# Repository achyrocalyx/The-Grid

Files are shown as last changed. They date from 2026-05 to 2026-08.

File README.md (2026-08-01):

# The-Grid
EC REX Small Build Project (Interactive LED Floor)

Funded in part by the Council for the Arts at MIT. [@artsatMIT](https://www.instagram.com/artsatmit/)


With generous support from [EasyEDA](https://easyeda.com/) and [JLCPCB](https://jlcpcb.com/) for PCB manufacturing.

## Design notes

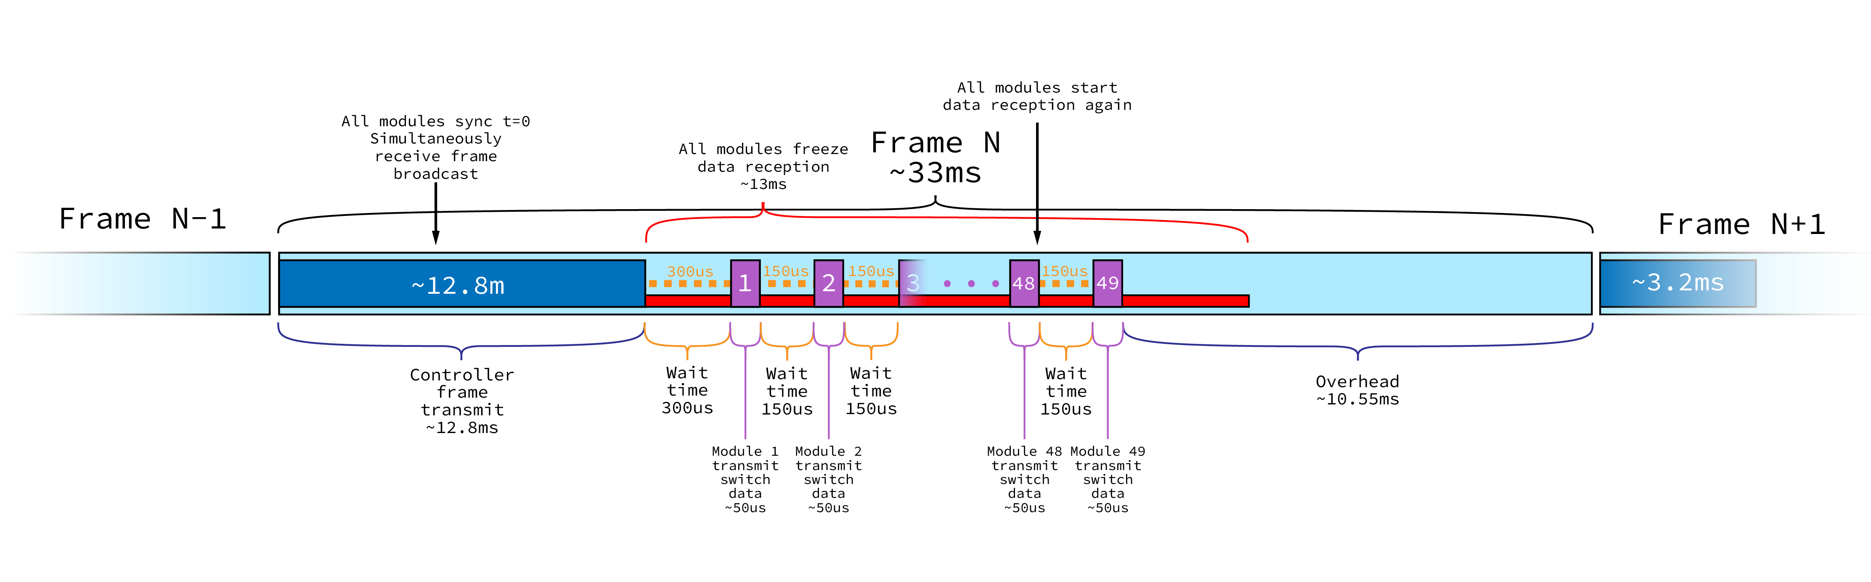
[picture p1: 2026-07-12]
FrameProtocolDraft2.png

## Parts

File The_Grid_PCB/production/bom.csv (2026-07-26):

Designator | Footprint | Quantity | Value | LCSC Part #
C1, C4, C6 | C_1206 | 3 | 4.7uF | C29823
C10, C11, C16, C17, C2, C3, C9 | C_0603 | 7 | 100nF | C14663
C12 | C_0805 | 1 | 1nF | C46653
C13 | C_0603 | 1 | 10pF | C1634
C14, C15 | C_1206 | 2 | 47uF | C96123
C18 | C_0805 | 1 | 10uF | C15850
C19 | C_0805 | 1 | 100nF | C28233
C5 | CP_Radial_D8.0mm_P3.50mm | 1 | 100uF | C112510
C7 | C_0805 | 1 | 10nF | C1710
C8 | C_0603 | 1 | 8.2nF | C1322360
D1 | D_0603 | 1 | LED | C2286
D2 | SOT-23 | 1 | CDSOT23-SM712 | C404012
D3 | D_SMA | 1 | SS34 | C8678
J1, J4 | TerminalBlock_MaiXu_MX126-5.0-02P_1x02_P5.00mm | 2 | Screw_Terminal_01x02 | C8404
J10, J11, J12, J13, J14, J15, J16, J5, J6, J7, J8, J9 | TerminalBlock_4Ucon_1x02_P3.50mm_Horizontal | 12 | Screw_Terminal_01x02 | C695629
J2, J3 | TerminalBlock_Xinya_XY308-2.54-3P_1x03_P2.54mm_Horizontal | 2 | Screw_Terminal_01x03 | C5188443
L1 | L_Bourns_SRP7028A_7.3x6.6mm | 1 | 8.2uH | C167222
Q1, Q10, Q11, Q12, Q2, Q3, Q4, Q5, Q6, Q7, Q8, Q9 | Q_SOT-23 | 12 | AO3400A | C20917
R1, R13 | R_0603 | 2 | 560Ω | C23204
R10, R12 | R_0603 | 2 | 200Ω | C8218
R11, R15, R16, R18, R2, R20, R22, R24, R26, R28, R3, R30, R32, R34, R36, R38, R40, R7, R8 | R_0603 | 19 | 10kΩ | C25804
R14 | R_0603 | 1 | 1.2kΩ | C22765
R17, R19, R21, R23, R25, R27, R29, R31, R33, R35, R37, R39 | R_0603 | 12 | 100Ω | C22775
R4, R5 | R_0603 | 2 | 10Ω | C22859
R9 | R_0603 | 1 | 68kΩ | C23231
TP1 | TestPoint_THTPad_D2.0mm_Drill1.0mm | 1 | RS485 RX
TP2 | TestPoint_THTPad_D2.0mm_Drill1.0mm | 1 | RS485 TX
TP3 | TestPoint_THTPad_D2.0mm_Drill1.0mm | 1 | 3V3
TP4 | TestPoint_THTPad_D2.0mm_Drill1.0mm | 1 | GND
TP5 | TestPoint_THTPad_D2.0mm_Drill1.0mm | 1 | 5V
U1 | STM32BluePill | 1 | STM32 Blue Pill
U2 | SOIC-8_3.9x4.9mm_P1.27mm | 1 | THDV1520 | C882408
U3 | SOIC127P600X175-8N | 1 | TPS54331DR | C9865

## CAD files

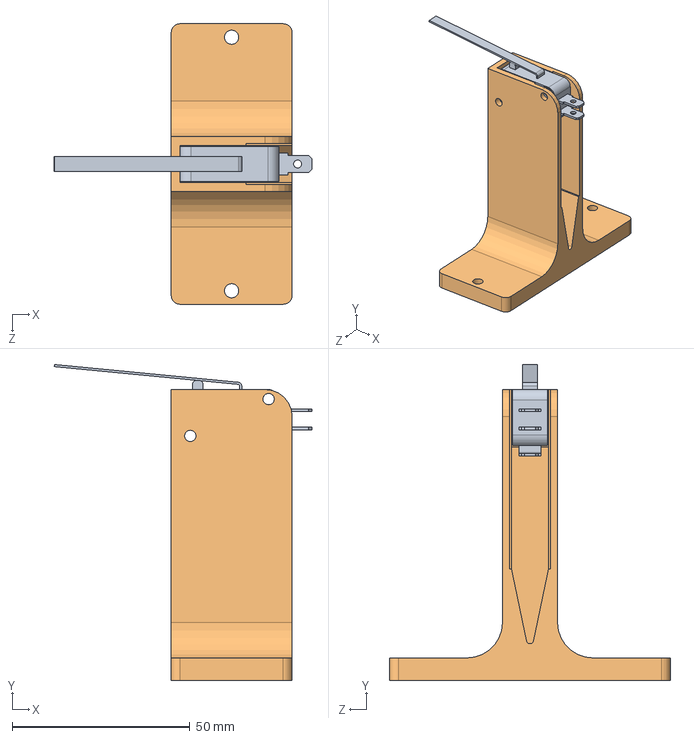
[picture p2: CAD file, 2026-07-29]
CAD/microswitch_assembly.SLDASM
72.5 x 88.9 x 79.0 mm
aliexpressMount
KW7_microswitch

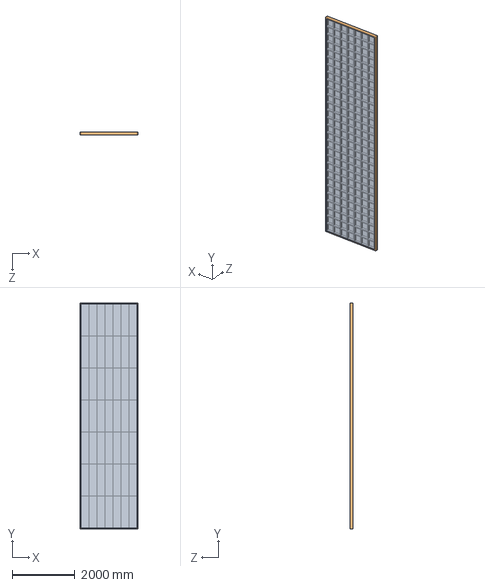
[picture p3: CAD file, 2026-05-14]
CAD/fullAssembly.SLDASM
1854.2 x 7188.2 x 88.9 mm
encloseDotModules
module cad REAL x 49

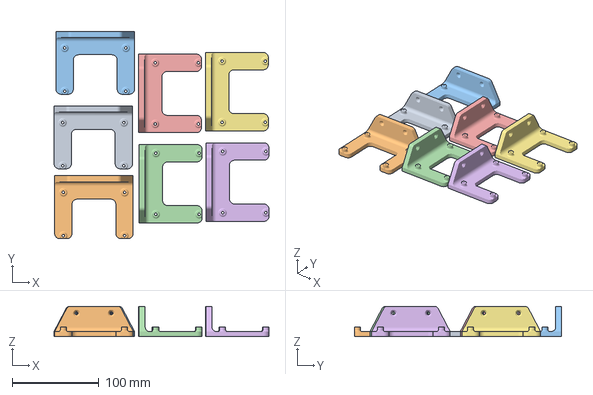
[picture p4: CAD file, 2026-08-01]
CAD/Printfiles/PCB_shelf_PRINTFILE.3mf
247.3 x 238.7 x 35.0 mm
PCB_shelf_step.STEP x 7

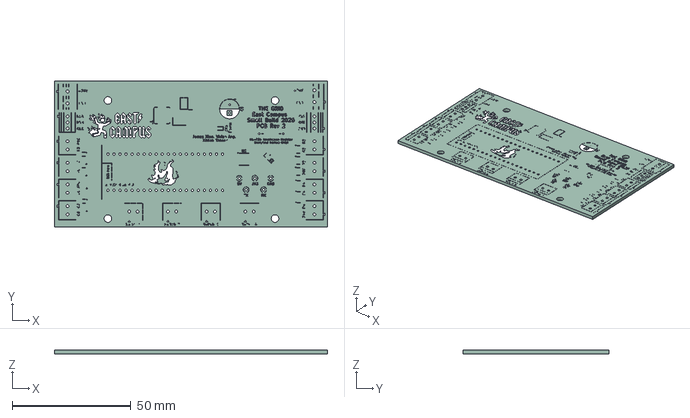
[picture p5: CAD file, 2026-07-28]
The_Grid_PCB/The_Grid_PCB.step
115.0 x 61.5 x 1.66 mm
The46A9_silkscreen x 2
The46A9_PCB

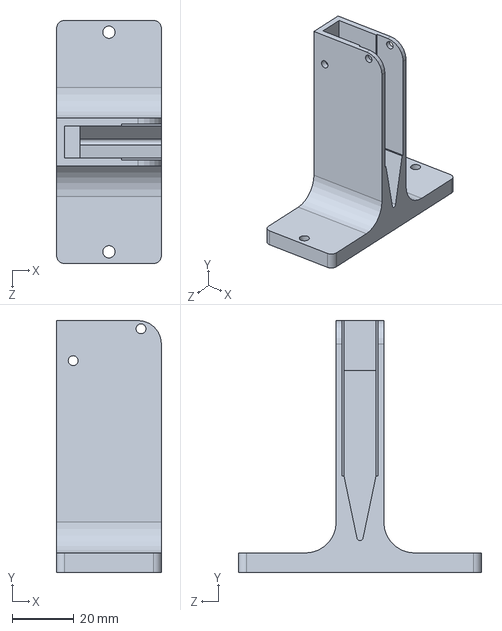
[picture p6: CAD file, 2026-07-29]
CAD/aliexpressMount.SLDPRT
34.1 x 81.9 x 79.0 mm

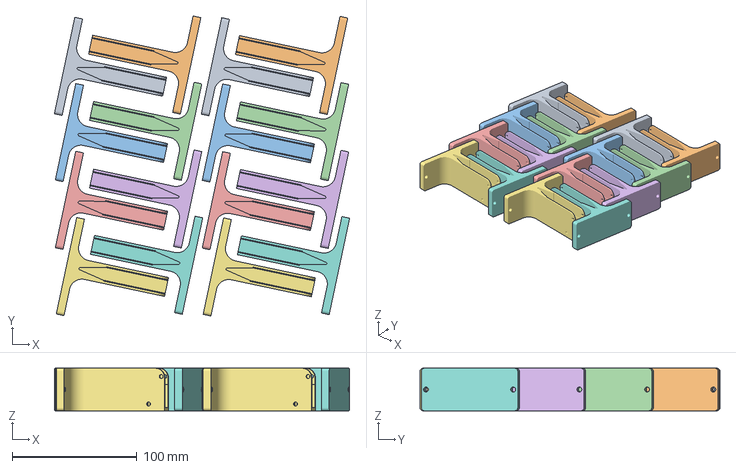
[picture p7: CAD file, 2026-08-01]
CAD/Printfiles/microswitch_mount_PRINTFILE.3mf
236.5 x 240.2 x 34.1 mm
aliexpress_mount_step.STEP x 16

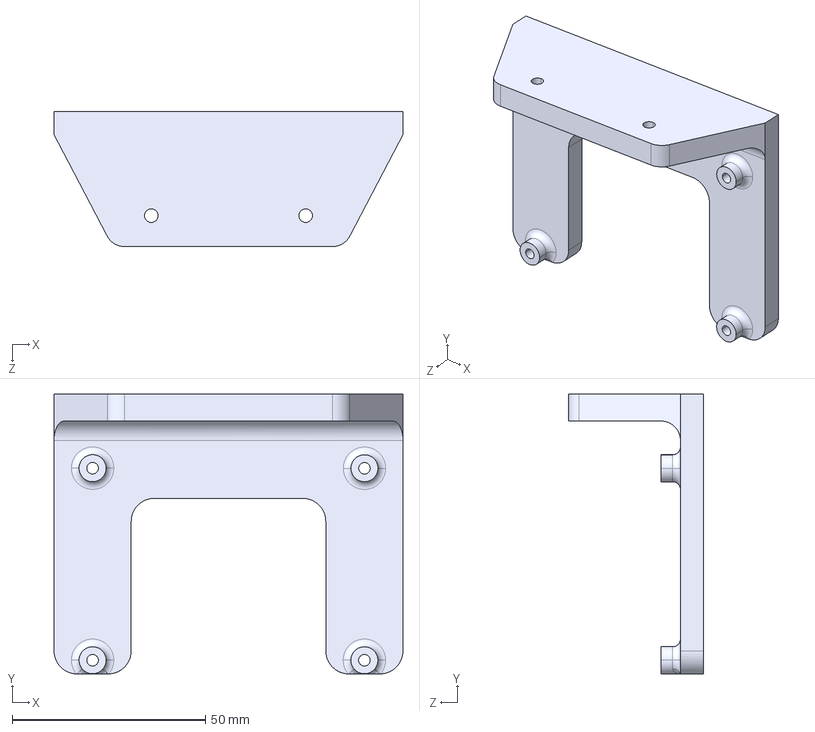
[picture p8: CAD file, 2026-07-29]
CAD/PCB_shelf_step.STEP
90.4 x 72.5 x 35.0 mm

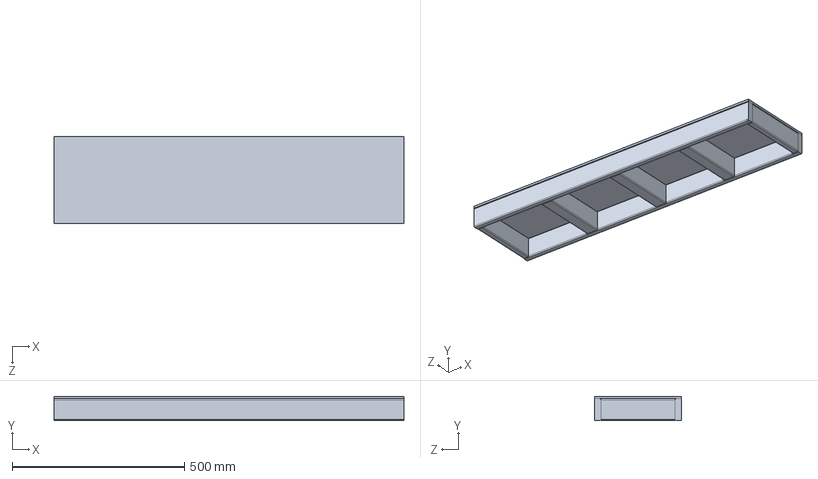
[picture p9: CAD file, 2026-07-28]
CAD/module cad REAL.SLDPRT
1016.0 x 69.8 x 254.0 mm

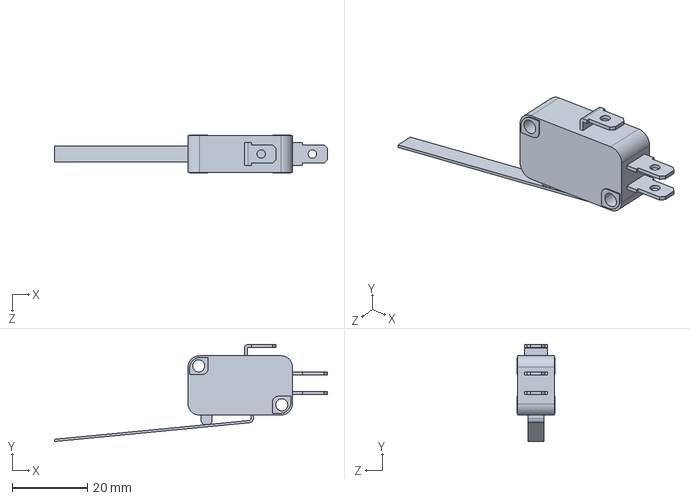
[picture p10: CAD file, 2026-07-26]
CAD/KW7_microswitch.SLDPRT
72.5 x 25.8 x 10.2 mm

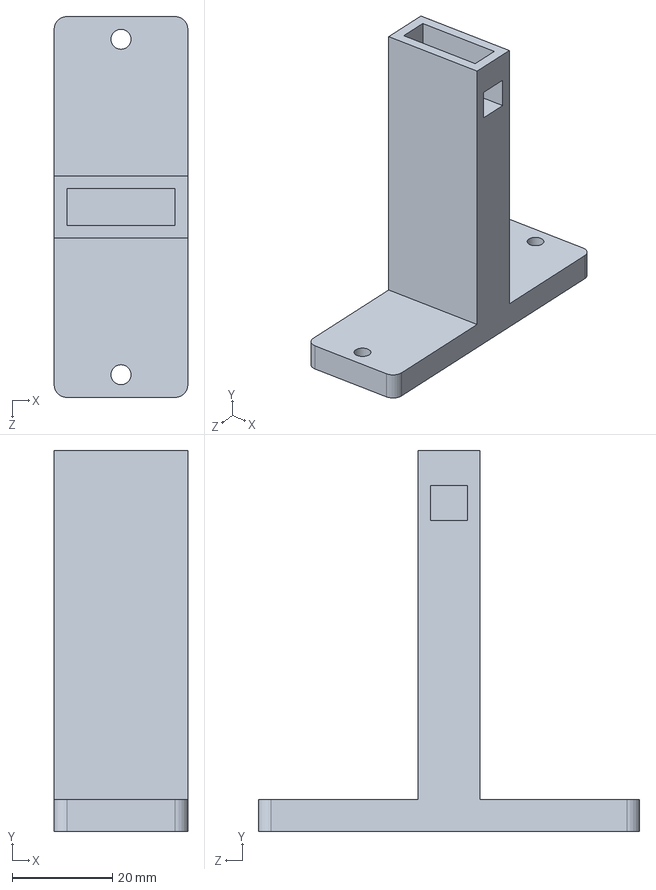
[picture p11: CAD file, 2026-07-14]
CAD/amazonMount.SLDPRT
26.7 x 75.9 x 75.9 mm

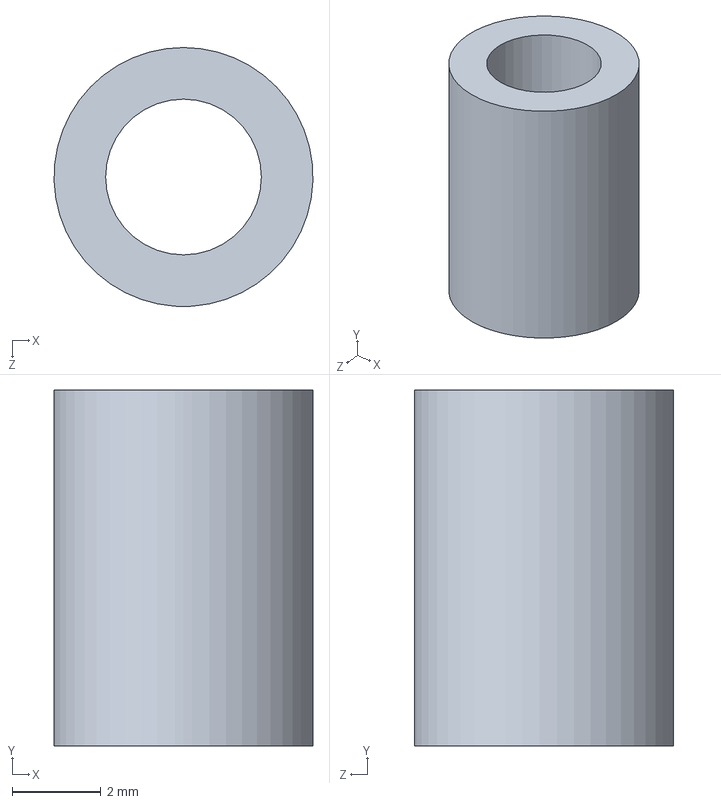
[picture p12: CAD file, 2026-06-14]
CAD/standoff.SLDPRT
5.82 x 8.00 x 5.82 mm

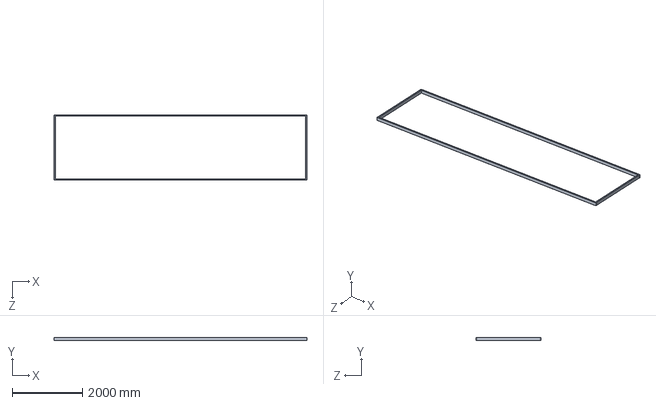
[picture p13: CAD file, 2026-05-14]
CAD/encloseDotModules.SLDPRT
7188.2 x 88.9 x 1854.2 mm

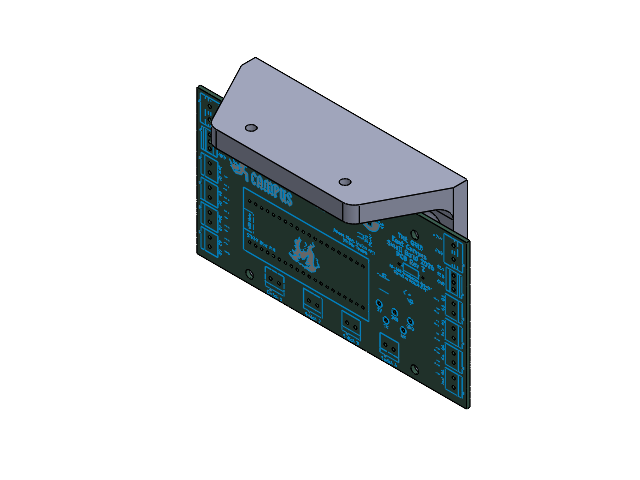
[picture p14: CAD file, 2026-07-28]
CAD/PCB_shelf_assembly.SLDASM
The46A9_silkscreen.step
The46A9_silkscreen-0.step
The46A9_PCB.step
PCB_shelf

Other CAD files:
CAD/aliexpress_mount_step.STEP
CAD/PCB_shelf.SLDPRT
CAD/standoff3MF.3MF
CAD/PCB_shelf_step.3mf
CAD/aliexpressMount.3MF

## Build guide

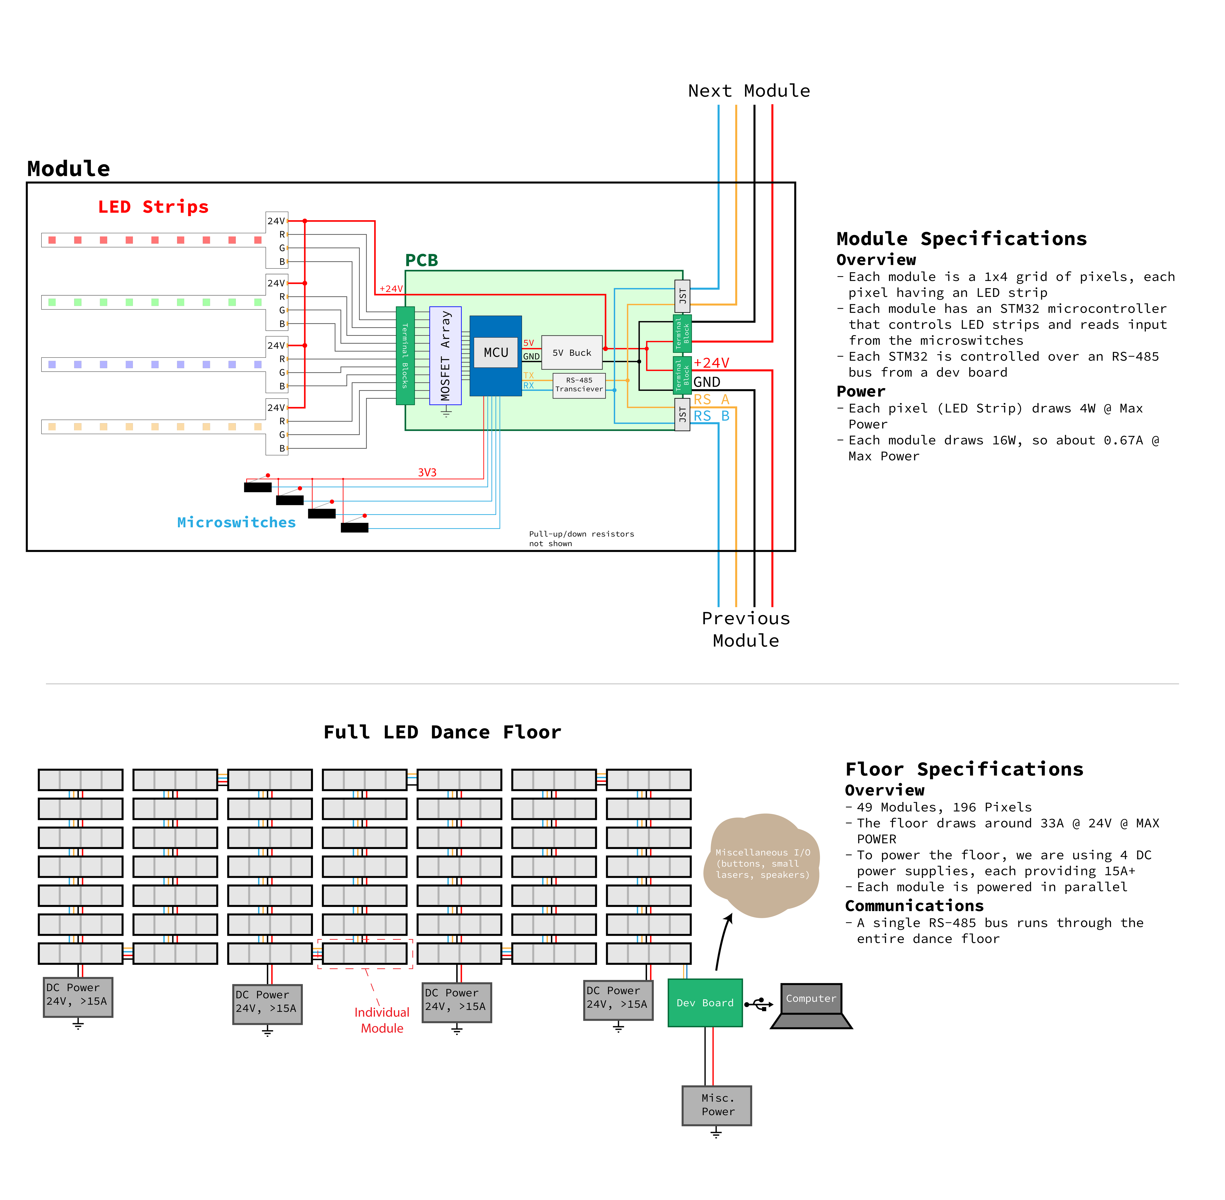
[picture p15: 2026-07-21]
WiringDiagramDraft5.png

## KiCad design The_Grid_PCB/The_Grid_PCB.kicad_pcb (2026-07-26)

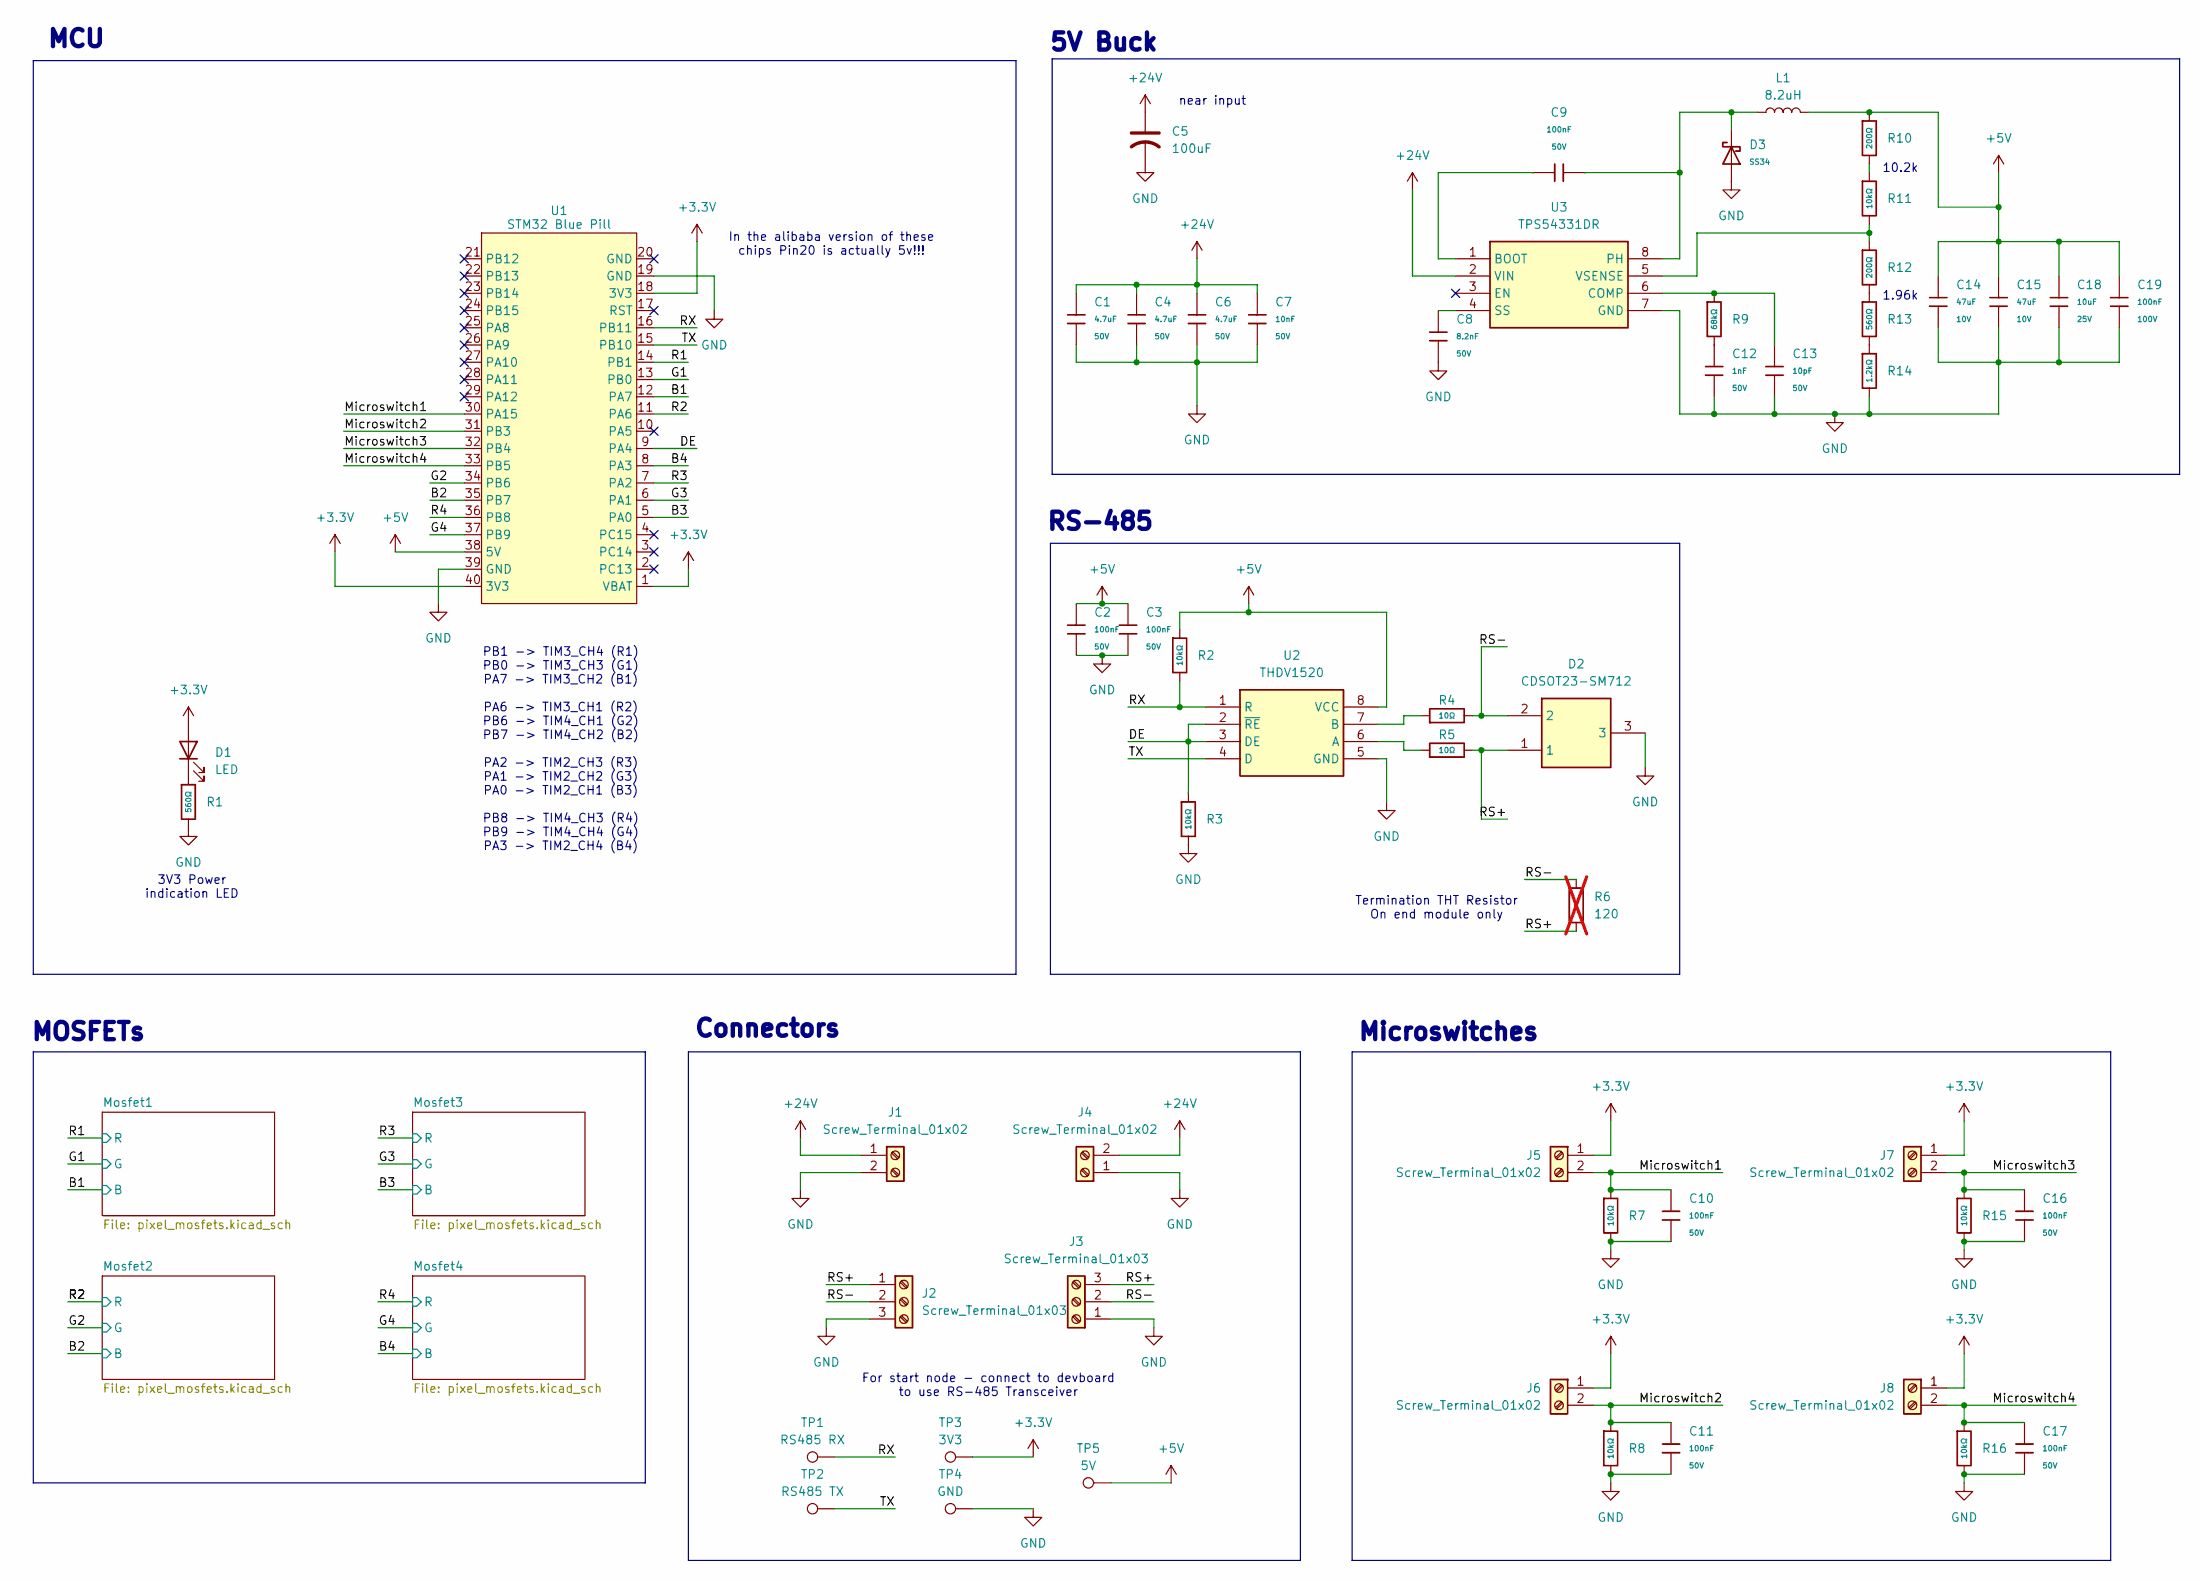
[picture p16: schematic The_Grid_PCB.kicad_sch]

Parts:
C1, C4, C6: 4.7uF; C_1206; Voltage Rated 50V; Tolerance ±10%; Part 1206B475K500NT; LCSC C29823
C2, C3, C9, C10, C11, C16, C17: 100nF; C_0603; Voltage Rated 50V; Tolerance ±10%; Part CC0603KRX7R9BB104; LCSC C14663
C5: 100uF; CP_Radial_D8.0mm_P3.50mm; LCSC C112510
C7: 10nF; C_0805; Voltage Rated 50V; Tolerance ±10%; Part CL21B103KBANNNC; LCSC C1710
C8: 8.2nF; C_0603; Voltage Rated 50V; Tolerance ±10%; Part 0603B822K500NT; LCSC C1322360
C12: 1nF; C_0805; Voltage Rated 50V; Tolerance ±10%; Part CL21B102KBCNNNC; LCSC C46653
C13: 10pF; C_0603; Voltage Rated 50V; Tolerance ±5%; Part CL10C100JB8NNNC; LCSC C1634
C14, C15: 47uF; C_1206; Voltage Rated 10V; Tolerance ±20%; Part CL31A476MPHNNNE; LCSC C96123
C18: 10uF; C_0805; Voltage Rated 25V; Tolerance ±10%; Part CL21A106KAYNNNE; LCSC C15850
C19: 100nF; C_0805; Voltage Rated 100V; Tolerance ±10%; Part CL21B104KCFNNNE; LCSC C28233
D1: LED; D_0603; LCSC C2286
D2: CDSOT23-SM712; SOT-23; Manufacturer_Part_Number CDSOT23-SM712; Mouser Part Number 652-CDSOT23-SM712
D3: SS34; D_SMA; Forward Voltage (Vf@If) 550mV@3A; Reverse Voltage (Vr) 40V; Part SS34; LCSC C8678
J1, J4: Screw_Terminal_01x02; TerminalBlock_MaiXu_MX126-5.0-02P_1x02_P5.00mm; LCSC C8404
J2, J3: Screw_Terminal_01x03; TerminalBlock_Xinya_XY308-2.54-3P_1x03_P2.54mm_Horizontal; LCSC C5188443
J5, J6, J7, J8: Screw_Terminal_01x02; TerminalBlock_4Ucon_1x02_P3.50mm_Horizontal; LCSC C695629
L1: 8.2uH; L_Bourns_SRP7028A_7.3x6.6mm; LCSC C167222
R1, R13: 560Ω; R_0603; Overload Voltage (Max) 75V; Tolerance ±1%; Part 0603WAF5600T5E; LCSC C23204
R2, R3, R7, R8, R11, R15, R16: 10kΩ; R_0603; Overload Voltage (Max) 75V; Tolerance ±1%; Part 0603WAF1002T5E; LCSC C25804
R4, R5: 10Ω; R_0603; Overload Voltage (Max) 75V; Tolerance ±1%; Part 0603WAF100JT5E; LCSC C22859
R6: 120; R_Axial_DIN0207_L6.3mm_D2.5mm_P10.16mm_Horizontal; not fitted
R9: 68kΩ; R_0603; Overload Voltage (Max) 75V; Tolerance ±1%; Part 0603WAF6802T5E; LCSC C23231
R10, R12: 200Ω; R_0603; Overload Voltage (Max) 75V; Tolerance ±1%; Part 0603WAF2000T5E; LCSC C8218
R14: 1.2kΩ; R_0603; Overload Voltage (Max) 75V; Tolerance ±1%; Part 0603WAF1201T5E; LCSC C22765
TP1: RS485 RX; TestPoint_THTPad_D2.0mm_Drill1.0mm
TP2: RS485 TX; TestPoint_THTPad_D2.0mm_Drill1.0mm
TP3: 3V3; TestPoint_THTPad_D2.0mm_Drill1.0mm
TP4: GND; TestPoint_THTPad_D2.0mm_Drill1.0mm
TP5: 5V; TestPoint_THTPad_D2.0mm_Drill1.0mm
U1: STM32 Blue Pill; STM32BluePill
U2: THDV1520; SOIC-8_3.9x4.9mm_P1.27mm; Manufacturer_Part_Number THDV1520; LCSC C882408
U3: TPS54331DR; SOIC127P600X175-8N; Manufacturer_Part_Number TPS54331DR; Mouser Part Number 595-TPS54331DR

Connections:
+3.3V: D1.2 (A), J5.1, J6.1, J7.1, J8.1, TP3.1 (1_1), U1.1 (VBAT), U1.18 (3V3), U1.40 (3V3)
+5V: C2.1, C3.1, C14.2, C15.2, C18.1, C19.1, L1.2, R2.1, R10.1, TP5.1 (1_1), U1.38 (5V), U2.8 (VCC)
+24V: C1.1, C4.1, C5.1, C6.1, C7.1, J1.1, J4.2, U3.2 (VIN); also elsewhere on the board
/B1: U1.12 (PA7); also elsewhere on the board
/B2: U1.35 (PB7); also elsewhere on the board
/B3: U1.5 (PA0); also elsewhere on the board
/B4: U1.8 (PA3); also elsewhere on the board
/DE: R3.1, U1.9 (PA4), U2.2 (~RE), U2.3 (DE)
/G1: U1.13 (PB0); also elsewhere on the board
/G2: U1.34 (PB6); also elsewhere on the board
/G3: U1.6 (PA1); also elsewhere on the board
/G4: U1.37 (PB9); also elsewhere on the board
/Microswitch1: C10.1, J5.2, R7.1, U1.30 (PA15)
/Microswitch2: C11.1, J6.2, R8.1, U1.31 (PB3)
/Microswitch3: C16.1, J7.2, R15.1, U1.32 (PB4)
/Microswitch4: C17.1, J8.2, R16.1, U1.33 (PB5)
/R1: U1.14 (PB1); also elsewhere on the board
/R2: U1.11 (PA6); also elsewhere on the board
/R3: U1.7 (PA2); also elsewhere on the board
/R4: U1.36 (PB8); also elsewhere on the board
/RS+: D2.1, J2.1, J3.3, R5.2, R6.2
/RS-: D2.2, J2.2, J3.2, R4.2, R6.1
/RX: R2.2, TP1.1 (1_1), U1.16 (PB11), U2.1 (R)
/TX: TP2.1 (1_1), U1.15 (PB10), U2.4 (D)
GND: C1.2, C2.2, C3.2, C4.2, C5.2, C6.2, C7.2, C8.2, C10.2, C11.2, C12.2, C13.2, C14.1, C15.1, C16.2, C17.2, C18.2, C19.2, D2.3, D3.2, J1.2, J2.3, J3.1, J4.1, R1.2, R3.2, R7.2, R8.2, R14.2, R15.2, R16.2, TP4.1 (1_1), U1.19 (GND), U1.39 (GND), U2.5 (GND), U3.7 (GND); also elsewhere on the board
unnamed: C12.1, R9.2
unnamed: D1.1 (K), R1.1
unnamed: R10.2, R11.1
unnamed: R12.2, R13.1
unnamed: R13.2, R14.1
unnamed: R5.1, U2.6 (A)
unnamed: R4.1, U2.7 (B)
unnamed: C9.1, U3.1 (BOOT)
unnamed: C13.1, R9.1, U3.6 (COMP)
unnamed: C9.2, D3.1, L1.1, U3.8 (PH)
unnamed: C8.1, U3.4 (SS)
unnamed: R11.2, R12.1, U3.5 (VSENSE)

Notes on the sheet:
RS-485
Connectors
1.96k
In the alibaba version of these chips Pin20 is actually 5v!!!
For start node - connect to devboard to use RS-485 Transceiver
3V3 Power indication LED
10.2k
5V Buck
near input
PB1 -> TIM3_CH4 (R1) PB0 -> TIM3_CH3 (G1) PA7 -> TIM3_CH2 (B1) PA6 -> TIM3_CH1 (R2) PB6 -> TIM4_CH1 (G2) PB7 -> TIM4_CH2 (B2) PA2 -> TIM2_CH3 (R3) PA1 -> TIM2_CH2 (G3) PA0 -> TIM2_CH1 (B3) PB8 -> TIM4_CH3 (R4) PB9 -> TIM4_CH4 (G4) PA3 -> TIM2_CH4 (B4)
MOSFETs
MCU
Termination THT Resistor On end module only
Microswitches

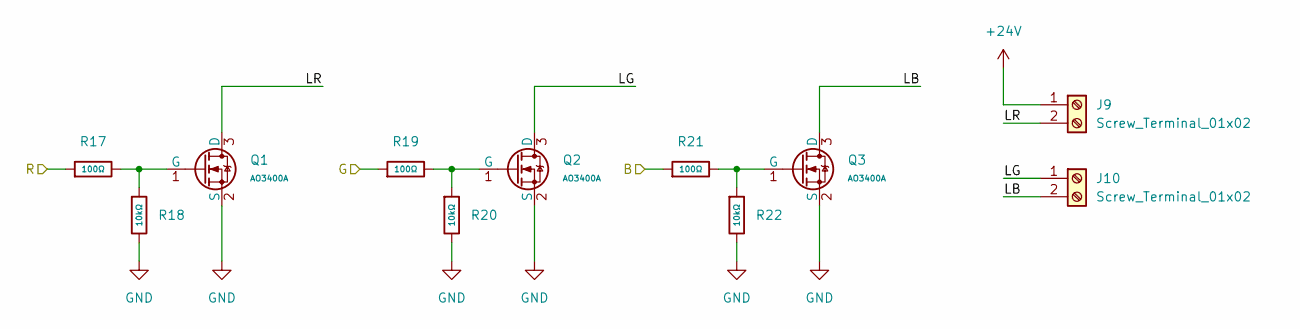
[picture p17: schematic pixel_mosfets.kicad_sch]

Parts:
J9, J10: Screw_Terminal_01x02; TerminalBlock_4Ucon_1x02_P3.50mm_Horizontal; LCSC C695629
Q1, Q2, Q3: AO3400A; Q_SOT-23; Part AO3400A; LCSC C20917
R17, R19, R21: 100Ω; R_0603; Overload Voltage (Max) 75V; Tolerance ±1%; Part 0603WAF1000T5E; LCSC C22775
R18, R20, R22: 10kΩ; R_0603; Overload Voltage (Max) 75V; Tolerance ±1%; Part 0603WAF1002T5E; LCSC C25804

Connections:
+24V: J9.1; also elsewhere on the board
/B1: R21.1; also elsewhere on the board
/G1: R19.1; also elsewhere on the board
/Mosfet1/LB: J10.2, Q3.3 (D)
/Mosfet1/LG: J10.1, Q2.3 (D)
/Mosfet1/LR: J9.2, Q1.3 (D)
/R1: R17.1; also elsewhere on the board
GND: Q1.2 (S), Q2.2 (S), Q3.2 (S), R18.2, R20.2, R22.2; also elsewhere on the board
unnamed: Q1.1 (G), R17.2, R18.1
unnamed: Q2.1 (G), R19.2, R20.1
unnamed: Q3.1 (G), R21.2, R22.1

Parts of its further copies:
J11, J12, J13, J14, J15, J16: Screw_Terminal_01x02; TerminalBlock_4Ucon_1x02_P3.50mm_Horizontal; LCSC C695629
Q4, Q5, Q6, Q7, Q8, Q9, Q10, Q11, Q12: AO3400A; Q_SOT-23; Part AO3400A; LCSC C20917
R23, R25, R27, R29, R31, R33, R35, R37, R39: 100Ω; R_0603; Overload Voltage (Max) 75V; Tolerance ±1%; Part 0603WAF1000T5E; LCSC C22775
R24, R26, R28, R30, R32, R34, R36, R38, R40: 10kΩ; R_0603; Overload Voltage (Max) 75V; Tolerance ±1%; Part 0603WAF1002T5E; LCSC C25804

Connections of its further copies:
+24V: J11.1, J13.1, J15.1; also elsewhere on the board
/B2: R27.1; also elsewhere on the board
/B3: R33.1; also elsewhere on the board
/B4: R39.1; also elsewhere on the board
/G2: R25.1; also elsewhere on the board
/G3: R31.1; also elsewhere on the board
/G4: R37.1; also elsewhere on the board
/Mosfet2/LB: J12.2, Q6.3 (D)
/Mosfet2/LG: J12.1, Q5.3 (D)
/Mosfet2/LR: J11.2, Q4.3 (D)
/Mosfet3/LB: J14.2, Q9.3 (D)
/Mosfet3/LG: J14.1, Q8.3 (D)
/Mosfet3/LR: J13.2, Q7.3 (D)
/Mosfet4/LB: J16.2, Q12.3 (D)
/Mosfet4/LG: J16.1, Q11.3 (D)
/Mosfet4/LR: J15.2, Q10.3 (D)
/R2: R23.1; also elsewhere on the board
/R3: R29.1; also elsewhere on the board
/R4: R35.1; also elsewhere on the board
GND: Q4.2 (S), Q5.2 (S), Q6.2 (S), Q7.2 (S), Q8.2 (S), Q9.2 (S), Q10.2 (S), Q11.2 (S), Q12.2 (S), R24.2, R26.2, R28.2, R30.2, R32.2, R34.2, R36.2, R38.2, R40.2; also elsewhere on the board
unnamed: Q4.1 (G), R23.2, R24.1
unnamed: Q5.1 (G), R25.2, R26.1
unnamed: Q6.1 (G), R27.2, R28.1
unnamed: Q7.1 (G), R29.2, R30.1
unnamed: Q8.1 (G), R31.2, R32.1
unnamed: Q9.1 (G), R33.2, R34.1
unnamed: Q10.1 (G), R35.2, R36.1
unnamed: Q11.1 (G), R37.2, R38.1
unnamed: Q12.1 (G), R39.2, R40.1

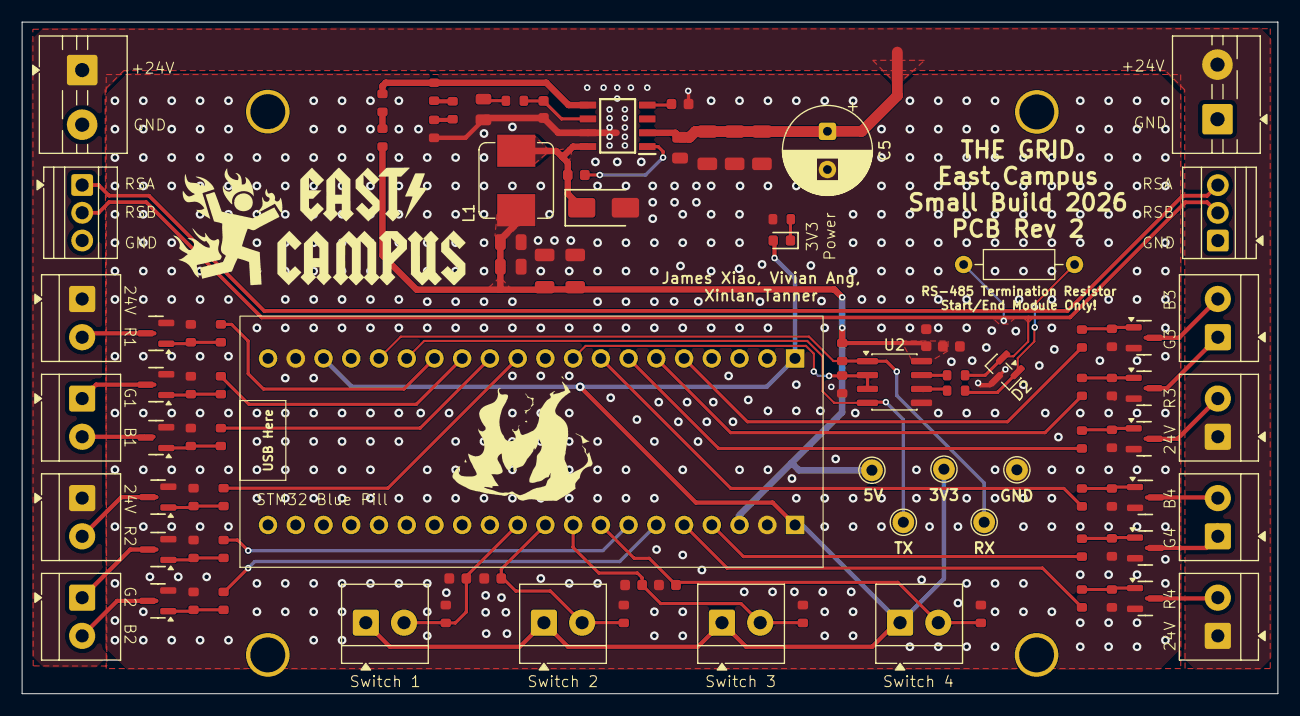
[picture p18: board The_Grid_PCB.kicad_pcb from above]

Board: 2 copper layers, 115.0 x 61.5 mm, 99 parts (0 on the bottom side), 61 nets.

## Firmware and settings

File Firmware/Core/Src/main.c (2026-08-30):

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
/* Includes ------------------------------------------------------------------*/
#include "main.h"

/* USER CODE BEGIN Includes */
#define MODULE_ID 7

/* USER CODE END Includes */

/* USER CODE BEGIN PD */
#define FRAME_DATA_LENGTH 589 // bytes
#define SWITCH_DATA_LENGTH 2 // bytes
/* USER CODE END PD */

TIM_HandleTypeDef htim1;
TIM_HandleTypeDef htim2;
TIM_HandleTypeDef htim3;
TIM_HandleTypeDef htim4;

UART_HandleTypeDef huart3;
DMA_HandleTypeDef hdma_usart3_rx;

/* USER CODE BEGIN PV */
uint8_t uart_rx_buffer[FRAME_DATA_LENGTH]; //rx buffer is 589 bytes
uint8_t uart_tx_buffer[SWITCH_DATA_LENGTH]; //tx buffer is 2 bytes

uint8_t microswitch[4] = {0}; //0 is off, 1 is on
uint8_t microswitch_off_next_cycle[4] = {0}; //set microswitch to be off on the next frame cycle

uint8_t microswitch_reported[4] = {0}; // reported values we send back to computer

uint8_t led_color_1[3]; // led color pixel [R val, G val, B val]
uint8_t led_color_2[3];
uint8_t led_color_3[3];
uint8_t led_color_4[3];

volatile uint8_t potentialMan[4] = {0}; // potentially microswitch may be on. slop variable to move while loop into main :(
volatile uint32_t timeStart[4] = {0};

volatile uint8_t resyncing = 0;
uint8_t sync_byte;

// state enums - idle, waiting, transmitted,
typedef enum {
	IDLE,
	WAITING,
	TRANSMITTED
} State;

typedef enum {
	RED,
	GREEN,
	BLUE
} Color;

State state = IDLE;


/* USER CODE END PV */

void SystemClock_Config(void);
static void MX_GPIO_Init(void);
static void MX_DMA_Init(void);
static void MX_TIM2_Init(void);
static void MX_TIM3_Init(void);
static void MX_TIM4_Init(void);
static void MX_USART3_UART_Init(void);
static void MX_TIM1_Init(void);
/* USER CODE BEGIN 0 */

/*== LED TIMER CHANNEL REFERENCE ==
PB1 -> TIM3_CH4 (R1)
PB0 -> TIM3_CH3 (G1)
PA7 -> TIM3_CH2 (B1)

PA6 -> TIM3_CH1 (R2)
PB6 -> TIM4_CH1 (G2)
PB7 -> TIM4_CH2 (B2)

PA2 -> TIM2_CH3 (R3)
PA1 -> TIM2_CH2 (G3)
PA0 -> TIM2_CH1 (B3)

PB8 -> TIM4_CH3 (R4)
PB9 -> TIM4_CH4 (G4)
PA3 -> TIM2_CH4 (B4) */

void command_led_1(uint8_t r, uint8_t g, uint8_t b) {
	led_color_1[RED] = r; // check protocol sheet for more information, sets colors to what is put in buffer (based on module ID)
	led_color_1[GREEN] = g;
	led_color_1[BLUE] = b;

	__HAL_TIM_SET_COMPARE(&htim3, TIM_CHANNEL_4, r);
	__HAL_TIM_SET_COMPARE(&htim3, TIM_CHANNEL_3, g);
	__HAL_TIM_SET_COMPARE(&htim3, TIM_CHANNEL_2, b);
}

void command_led_2(uint8_t r, uint8_t g, uint8_t b) {
	led_color_2[RED] = r;
	led_color_2[GREEN] = g;
	led_color_2[BLUE] = b;

	__HAL_TIM_SET_COMPARE(&htim3, TIM_CHANNEL_1, r);
	__HAL_TIM_SET_COMPARE(&htim4, TIM_CHANNEL_1, g);
	__HAL_TIM_SET_COMPARE(&htim4, TIM_CHANNEL_2, b);
}

void command_led_3(uint8_t r, uint8_t g, uint8_t b) {
	led_color_3[RED] = r;
	led_color_3[GREEN] = g;
	led_color_3[BLUE] = b;

	__HAL_TIM_SET_COMPARE(&htim2, TIM_CHANNEL_3, r);
	__HAL_TIM_SET_COMPARE(&htim2, TIM_CHANNEL_2, g);
	__HAL_TIM_SET_COMPARE(&htim2, TIM_CHANNEL_1, b);
}

void command_led_4(uint8_t r, uint8_t g, uint8_t b) {
	led_color_4[RED] = r;
	led_color_4[GREEN] = g;
	led_color_4[BLUE] = b;

	__HAL_TIM_SET_COMPARE(&htim4, TIM_CHANNEL_3, r);
	__HAL_TIM_SET_COMPARE(&htim4, TIM_CHANNEL_4, g);
	__HAL_TIM_SET_COMPARE(&htim2, TIM_CHANNEL_4, b);
}

/* USER CODE END 0 */

/**
  * @brief  The application entry point.
  * @retval int
  */
int main(void)
{

  /* MCU Configuration--------------------------------------------------------*/

  /* Reset of all peripherals, Initializes the Flash interface and the Systick. */
  HAL_Init();

  /* Configure the system clock */
  SystemClock_Config();

  /* USER CODE BEGIN SysInit */
  __HAL_RCC_AFIO_CLK_ENABLE();
  __HAL_AFIO_REMAP_SWJ_NOJTAG();   // releases JTAG-only pins (PA15, PB3, PB4) for GPIO use, keeps SWD (PA13/PA14) alive for debugging
  /* USER CODE END SysInit */

  /* Initialize all configured peripherals */
  MX_GPIO_Init();
  MX_DMA_Init();
  MX_TIM2_Init();
  MX_TIM3_Init();
  MX_TIM4_Init();
  MX_USART3_UART_Init();
  MX_TIM1_Init();
  /* USER CODE BEGIN 2 */

  /* Enable PWM Timers */
    HAL_TIM_PWM_Start(&htim2, TIM_CHANNEL_1);
    HAL_TIM_PWM_Start(&htim2, TIM_CHANNEL_2);
    HAL_TIM_PWM_Start(&htim2, TIM_CHANNEL_3);
    HAL_TIM_PWM_Start(&htim2, TIM_CHANNEL_4);

    HAL_TIM_PWM_Start(&htim3, TIM_CHANNEL_1);
    HAL_TIM_PWM_Start(&htim3, TIM_CHANNEL_2);
    HAL_TIM_PWM_Start(&htim3, TIM_CHANNEL_3);
    HAL_TIM_PWM_Start(&htim3, TIM_CHANNEL_4);

    HAL_TIM_PWM_Start(&htim4, TIM_CHANNEL_1);
    HAL_TIM_PWM_Start(&htim4, TIM_CHANNEL_2);
    HAL_TIM_PWM_Start(&htim4, TIM_CHANNEL_3);
    HAL_TIM_PWM_Start(&htim4, TIM_CHANNEL_4);

    HAL_TIM_Base_Start(&htim1);

    HAL_UART_Receive_DMA(&huart3, uart_rx_buffer, FRAME_DATA_LENGTH); // Initialize receiving

    HAL_GPIO_WritePin(GPIOA, GPIO_PIN_4, GPIO_PIN_RESET); // data enable low

  /* USER CODE END 2 */

  /* Infinite loop */
  /* USER CODE BEGIN WHILE */
  while (1)
  {

	  // microswitch sensing
		if (potentialMan[0] == 1) {
			if (HAL_GPIO_ReadPin(GPIOA, GPIO_PIN_15) == GPIO_PIN_RESET) {
				microswitch[0] = 0;
			}
			else if (HAL_GetTick() - timeStart[0] >= 10) {
				/* MICROSWITCH HAS BEEN PRESSED */
				microswitch_off_next_cycle[0] = 0;
				microswitch[0] = 1;
				microswitch_reported[0] = 1;
				potentialMan[0] = 0;
			}
		}
		if (microswitch[0] == 1 || microswitch_reported[0] == 1) {
			if (HAL_GPIO_ReadPin(GPIOA, GPIO_PIN_15) == GPIO_PIN_RESET) {
				/* MICROSWITCH IS NOT PRESSED */
				microswitch[0] = 0;
				microswitch_off_next_cycle[0] = 1;
			}
		}

		if (potentialMan[1] == 1) {
			if (HAL_GPIO_ReadPin(GPIOB, GPIO_PIN_3) == GPIO_PIN_RESET) {
				microswitch[1] = 0;
			}
			else if (HAL_GetTick() - timeStart[1] >= 10) {
				/* MICROSWITCH HAS BEEN PRESSED */
				microswitch_off_next_cycle[1] = 0;
				microswitch[1] = 1;
				microswitch_reported[1] = 1;
				potentialMan[1] = 0;
			}
		}
		if (microswitch[1] == 1 || microswitch_reported[1] == 1) {
			if (HAL_GPIO_ReadPin(GPIOB, GPIO_PIN_3) == GPIO_PIN_RESET) {
				/* MICROSWITCH IS NOT PRESSED */
				microswitch[1] = 0;
				microswitch_off_next_cycle[1] = 1;
			}
		}

		if (potentialMan[2] == 1) {
			if (HAL_GPIO_ReadPin(GPIOB, GPIO_PIN_4) == GPIO_PIN_RESET) {
				microswitch[2] = 0;
			}
			else if (HAL_GetTick() - timeStart[2] >= 10) {
				/* MICROSWITCH HAS BEEN PRESSED */
				microswitch_off_next_cycle[2] = 0;
				microswitch[2] = 1;
				microswitch_reported[2] = 1;
				potentialMan[2] = 0;
			}
		}
		if (microswitch[2] == 1 || microswitch_reported[2] == 1) {
			if (HAL_GPIO_ReadPin(GPIOB, GPIO_PIN_4) == GPIO_PIN_RESET) {
				/* MICROSWITCH IS NOT PRESSED */
				microswitch[2] = 0;
				microswitch_off_next_cycle[2] = 1;
			}
		}

		if (potentialMan[3] == 1) {
			if (HAL_GPIO_ReadPin(GPIOB, GPIO_PIN_5) == GPIO_PIN_RESET) {
				microswitch[3] = 0;
			}
			else if (HAL_GetTick() - timeStart[3] >= 10) {
				/* MICROSWITCH HAS BEEN PRESSED */
				microswitch_off_next_cycle[3] = 0;
				microswitch[3] = 1;
				microswitch_reported[3] = 1;
				potentialMan[3] = 0;
			}
		}
		if (microswitch[3] == 1 || microswitch_reported[3] == 1) {
			if (HAL_GPIO_ReadPin(GPIOB, GPIO_PIN_5) == GPIO_PIN_RESET) {
				/* MICROSWITCH IS NOT PRESSED */
				microswitch[3] = 0;
				microswitch_off_next_cycle[3] = 1;
			}
		}

	  if (state == WAITING) {
		  if ((TIM1 -> CNT) > (300 + ((50 + 150) * (MODULE_ID - 1)))) {
			  /* Format tx data buffer */
			  uart_tx_buffer[0] = MODULE_ID;
			  uart_tx_buffer[1] = (microswitch_reported[3] << 3) | (microswitch_reported[2] << 2) | (microswitch_reported[1] << 1) | (microswitch_reported[0] << 0);

//			  HAL_UART_Transmit_IT(&huart3, uart_tx_buffer, SWITCH_DATA_LENGTH);
			  if (uart_tx_buffer[1]) {
				  HAL_GPIO_WritePin(GPIOA, GPIO_PIN_4, GPIO_PIN_SET); // data enable high
				  HAL_UART_Transmit(&huart3, uart_tx_buffer, SWITCH_DATA_LENGTH, 10);
				  HAL_GPIO_WritePin(GPIOA, GPIO_PIN_4, GPIO_PIN_RESET); // pull DE low
			  }
			  state = TRANSMITTED;
		  }
	  }
	  if (TIM1 -> CNT > 13000 && state != IDLE) { // if timer > 13ms
		  __HAL_TIM_SET_COUNTER(&htim1,0); // re-start millisecond timer @ 0
		  HAL_UART_Receive_DMA(&huart3, uart_rx_buffer, FRAME_DATA_LENGTH); // restart listening to UART
		  state = IDLE;
	  }

	  static uint32_t last_switch_clear_tick = 0;
	  if (HAL_GetTick() - last_switch_clear_tick >= 33) {  // ~33ms, reset once per frame
	      last_switch_clear_tick = HAL_GetTick();
	      for (int i = 0; i < 4; i++) {
	          if (microswitch_off_next_cycle[i]) {
	              microswitch_reported[i] = 0;
	              microswitch_off_next_cycle[i] = 0;
	          }
	      }
	  }

    /* USER CODE END WHILE */

    /* USER CODE BEGIN 3 */
  }
  /* USER CODE END 3 */
}

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
/* USER CODE BEGIN 4 */

void HAL_UART_ErrorCallback(UART_HandleTypeDef *huart) {
    __HAL_UART_CLEAR_PEFLAG(huart);
    resyncing = 1;
    HAL_UART_Receive_IT(&huart3, &sync_byte, 1);  // fall back to byte-scan resync
}

/* UART Receive Callback */
void HAL_UART_RxCpltCallback(UART_HandleTypeDef *huart) { // when rx buffer is filled, this function will get called -- ie when biiig frame transmit guy done
	if (resyncing) {
        // scanning one byte at a time looking for 0xFF
        if (sync_byte == 0xFF) {
            resyncing = 0;
            uart_rx_buffer[0] = 0xFF;
            // receive the REMAINING 588 bytes into slot 1 onward
            HAL_UART_Receive_DMA(&huart3, &uart_rx_buffer[1], FRAME_DATA_LENGTH - 1);
        } else {
            HAL_UART_Receive_IT(&huart3, &sync_byte, 1); // keep scanning
        }
        return;
	}

	if (uart_rx_buffer[0] == 0xFF && state == IDLE) { // if header matches and state is idle
		state = WAITING;
		__HAL_TIM_SET_COUNTER(&htim1,0); // start millisecond timer @ 0

		command_led_1(uart_rx_buffer[(MODULE_ID * 12) - 11],
					  uart_rx_buffer[(MODULE_ID * 12) - 11 + 1],
					  uart_rx_buffer[(MODULE_ID * 12) - 11 + 2]);

		command_led_2(uart_rx_buffer[(MODULE_ID * 12) - 11 + 3],
					  uart_rx_buffer[(MODULE_ID * 12) - 11 + 4],
					  uart_rx_buffer[(MODULE_ID * 12) - 11 + 5]);

		command_led_3(uart_rx_buffer[(MODULE_ID * 12) - 11 + 6],
					  uart_rx_buffer[(MODULE_ID * 12) - 11 + 7],
					  uart_rx_buffer[(MODULE_ID * 12) - 11 + 8]);

		command_led_4(uart_rx_buffer[(MODULE_ID * 12) - 11 + 9],
					  uart_rx_buffer[(MODULE_ID * 12) - 11 + 10],
					  uart_rx_buffer[(MODULE_ID * 12) - 11 + 11]);
	}
	else {
        // misaligned frame, do byte-scan resync until we hit header frame
        resyncing = 1;
        HAL_UART_Receive_IT(&huart3, &sync_byte, 1);
	}
}

void HAL_UART_TxCpltCallback(UART_HandleTypeDef *huart) { // tx callback
	HAL_GPIO_WritePin(GPIOA, GPIO_PIN_4, GPIO_PIN_RESET); //pull DE low
}

/* MICROSWITCH INTERRUPT */
void HAL_GPIO_EXTI_Callback(uint16_t GPIO_Pin) {
	if (GPIO_Pin == GPIO_PIN_15) {
		potentialMan[0] = 1;
		timeStart[0] = HAL_GetTick();
	}
	if (GPIO_Pin == GPIO_PIN_3) {
		potentialMan[1] = 1;
		timeStart[1] = HAL_GetTick();
	}
	if (GPIO_Pin == GPIO_PIN_4) {
		potentialMan[2] = 1;
		timeStart[2] = HAL_GetTick();
	}
	if (GPIO_Pin == GPIO_PIN_5) {
		potentialMan[3] = 1;
		timeStart[3] = HAL_GetTick();
	}
}


/* USER CODE END 4 */
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


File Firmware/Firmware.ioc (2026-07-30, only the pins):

Mcu.UserName=STM32F103C8Tx
PA0-WKUP.Signal=S_TIM2_CH1_ETR
PA1.Signal=S_TIM2_CH2
PA15.Signal=GPXTI15
PA2.Signal=S_TIM2_CH3
PA3.Signal=S_TIM2_CH4
PA4.Signal=GPIO_Output
PA6.Signal=S_TIM3_CH1
PA7.Signal=S_TIM3_CH2
PB0.Signal=S_TIM3_CH3
PB1.Signal=S_TIM3_CH4
PB10.Signal=USART3_TX
PB11.Signal=USART3_RX
PB3.Signal=GPXTI3
PB4.Signal=GPXTI4
PB5.Signal=GPXTI5
PB6.Signal=S_TIM4_CH1
PB7.Signal=S_TIM4_CH2
PB8.Signal=S_TIM4_CH3
PB9.Signal=S_TIM4_CH4
PD0-OSC_IN.Signal=RCC_OSC_IN
PD1-OSC_OUT.Signal=RCC_OSC_OUT

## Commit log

2026-05-02 iter 1 minus capacitor stuff
    [The_Grid_PCB.kicad_pcb, The_Grid_PCB.kicad_sch, pixel_mosfets.kicad_sch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]
2026-05-02 update custom symbols
    [The_Grid_PCB.kicad_sch, pixel_mosfets.kicad_sch]
2026-05-03 module CAD
    [module cad REAL.SLDPRT]
2026-05-04 draft 1 schematic
    [The_Grid_PCB.kicad_sch, switch.kicad_sch]
2026-05-10 pcb iter 1 done
    [The_Grid_PCB.kicad_pcb, The_Grid_PCB.kicad_sch, bom.csv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]
2026-05-10 upload wiring diagram
2026-05-13 updated CAD
    [encloseDotModules.SLDPRT, fullAssembly.SLDASM, module cad REAL.SLDPRT]
2026-05-13 better organization (aka one folder)
    [encloseDotModules.SLDPRT, fullAssembly.SLDASM, module cad REAL.SLDPRT]
2026-05-14 update wiring diagram again sob
    [The_Grid_PCB.kicad_pcb, The_Grid_PCB.kicad_sch, pixel_mosfets.kicad_sch]
2026-05-31 revised pcb nevin/miguel feedback
    [The_Grid_PCB.kicad_pcb, The_Grid_PCB.kicad_sch, pixel_mosfets.kicad_sch]
2026-05-31 add silkscreen, move termination res
    [The_Grid_PCB.kicad_pcb]
2026-05-31 edit silkscreen
    [The_Grid_PCB.kicad_pcb]
2026-06-03 rev1 pcb sent to prod
    [The_Grid_PCB.kicad_pcb, The_Grid_PCB.kicad_sch, bom.csv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]
2026-06-14 microswitch 1 controls led rainbow 1
2026-06-14 standoff cad
    [standoff.SLDPRT]
2026-06-14 standoff cad but 3mf file this time :(
    [standoff.3MF]
2026-06-14 standoff hole too small :()
    [mount3mf.3MF, standoff.3MF, standoff.SLDPRT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]
2026-06-14 mount 2.0
    [badmount3MF.3MF, badmountlol.SLDPRT]
2026-06-17 2pixel with 100ms req time, still does not fix aoe bug
    [TheGridTesting.ioc, main.c]
2026-06-26 frame protocol diagram
2026-07-09 pcb impedence matching, switch cap filtering, mounting holes, silkscreen updates
    [The_Grid_PCB.kicad_pcb, The_Grid_PCB.kicad_sch]
2026-07-10 rev2 minus silkscreen
    [The_Grid_PCB.kicad_pcb, The_Grid_PCB.kicad_sch, pixel_mosfets.kicad_sch]
2026-07-11 more cad ITS SO OVER
    [aliexpressMount.3MF, aliexpressMount.SLDPRT, amazonMount.SLDPRT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]
2026-07-12 update frame protocol diagram
2026-07-21 pcb rev 2 ready for fab (?)
    [The_Grid_PCB.kicad_pcb, bom.csv, designators.csv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]
2026-07-26 pcb rev2 sent to fab
    [The_Grid_PCB.kicad_pcb, The_Grid_PCB.kicad_sch, bom.csv]
2026-07-26 babys first solidworks experience (import and modify kw7 switch)
    [KW7_microswitch.SLDPRT]
2026-07-28 new microswitch mount
    [aliexpressMount.SLDPRT, microswitch_assembly.SLDASM]
2026-07-28 shelf v1
    [PCB_shelf.SLDPRT, PCB_shelf_assembly.SLDASM, The_Grid_PCB.step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]
2026-07-28 its xiao build against the sun and we will Win
    [16_microswitch_mount_3dp.3mf, aliexpressMount.SLDPRT, aliexpress_mount_step.3mf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]
2026-07-29 1000000 goons are coming your way click to affirm
    [16_microswitch_mount_3dp.3mf, PCB_shelf_step.STEP, aliexpressMount.SLDPRT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]
2026-07-30 allnighter grind sesh oh em jeeee but the module protocol is implemented and the controller firmware is also implemented and there are a billion bugs that i needed to catch and there are a billion mo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
    [30fps_testing.py, Firmware.ioc, FirmwareController.ioc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]
2026-08-30 rainbow test script
    [The_Grid_PCB.step]

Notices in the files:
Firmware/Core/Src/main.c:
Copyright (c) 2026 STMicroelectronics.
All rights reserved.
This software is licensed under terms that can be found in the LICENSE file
